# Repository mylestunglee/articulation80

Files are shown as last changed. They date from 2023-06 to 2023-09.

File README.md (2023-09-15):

# articulation80

The _articulation80_ keyboard is a split keyboard with 4x9 column splayed keys and 4 thumb keys. The name is inspired from articulated buses, where this keyboard has many connected blocks.

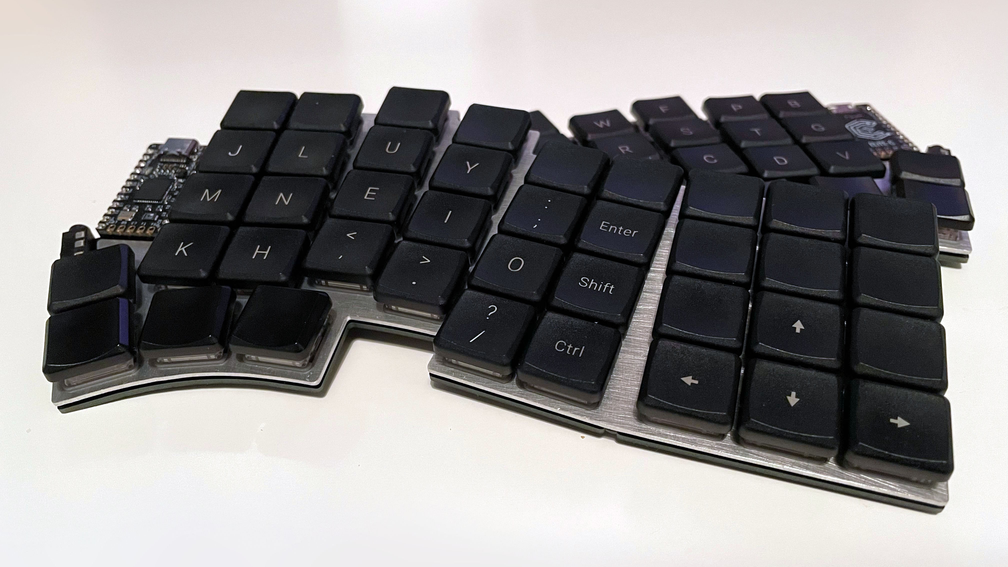
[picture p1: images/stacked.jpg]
Keyboard preview


It features:
- Kailh Choc V1 hotswap support with choc spacing
- A detachable inner number row with fixed outer number row
- A detachable numpad
- Serial or I2C connection between halves
- Pro Micro-compatible controller support
- No branding! If you are building this, you may want to add silk-screen to make soldering easier.

I took inspiration from many keyboards:
- The general snappable layout from [Breeze](https://www.afternoonlabs.com/breeze/)
- The pinky stagger from [Kyria](https://blog.splitkb.com/introducing-the-kyria/)
- The column splay and thumb cluster from [Hillside 52](https://github.com/mmccoyd/hillside)
- Many popular keyboards to determine a suitable wiring diagram for TRRS, such as the [Corne](https://github.com/foostan/crkbd)

## Repository Contents

| Name | Description |
|:-|:-|
| `pcb` | KiCad 7 project with symbol diagrams, footprints and 3D models included |
| `layout.FCStd` | FreeCad layout file outlining PCB and plate edges |
| `articulation80` | QMK files for firmware |

`scripts/info_json_matrix`

Generates `info.json` layout data for QMK by running `python generate_layout.py layout.csv`. `layout.csv` maps the visual key position with the pin row and column.

`scripts/verify_geometry`

 Translates points generated by FreeCad into KiCad. `export_points.py` is a script intended to run inside FreeCad to export all points into a text file, called `geometry.txt`. `update_geometry_markers.py` uses `geometry.txt` to aid the correct placement of components on the PCB and edges by placing dummy components as markers. Using the snap tool in KiCad, one can construct the edge by connecting markers. `remove_geometry_markers.py` removes these markers. Perhaps there is a more efficient way to make FreeCad and KiCad work together with existing plugins.

After soldering, copy the `articulation80` sub-directory into `qmk_firmware/keyboards`. Flash with:
```
qmk flash -kb articulation80 -km default -bl dfu-split-left
```
Replace `left` with `right` as necessary. This command assumes the Elite-C has been soldered using I2C. If not, change the bootloader in the command and in the `info.json` file.

## Build Instructions

This build is very similar to existing keyboards. Please refer to the inspired keyboards for full instructions.

### Build Parts

| Name | Count | Remarks |
|:-|:-|:-|
| PCB | 2 | |
| Plate | 2 | Ensure left and right are cut as required |
| Controller | 2 | A Pro Micro-compatible controller |
| TRRS jack | 2 | PJ-320A, ensure pins are through-hole|
| TRRS cable | 1 | Also called a 4-pin 3.5mm audio auxiliary cable |
| Reset button | 2 | Optional, PTS526 SM15 SMTR2 LFS recommended|
| Resistors | 2 | Optional, for I2C connection, RC1206FR-074K7 |
| Diode | 80* | SMD only, 1N4148W-TP, SOD-123 recommended |
| Hot swap key sockets | 80* | CPG135001S30 |
| Key Switch | 80* | |
| Key Cap | 80* | Ideally 6 key caps for thumbs |
| Hot swap controller sockets | 4 | Optional, 315-43-112-41-003000 or higher profile.|
| Hot swap pins | 48 | Optional, 3320-0-00-15-00-00-03-0 |
| Rubber feet | 12 | Can have more for stability, 6 recommended minimum for each side. SJ-5302 CLEAR recommended. |

*Adjust for number of keys desired.

See the [documentation on QMK](https://github.com/qmk/qmk_firmware/blob/master/docs/feature_split_keyboard.md) for how to solder the resistors. To minimise the complexity of the PCB, the left side controller is soldered upside down. There are four pads which connect the controller to the TRRS jack, these are intended to be soldered on the back side of the keyboard. From left to right with the back side facing up, if using serial connection, solder pads 1 and 4, otherwise if using I2C, solder 2, 3 and 4.

## More Images

Featuring MBK and MCC POM keycaps.

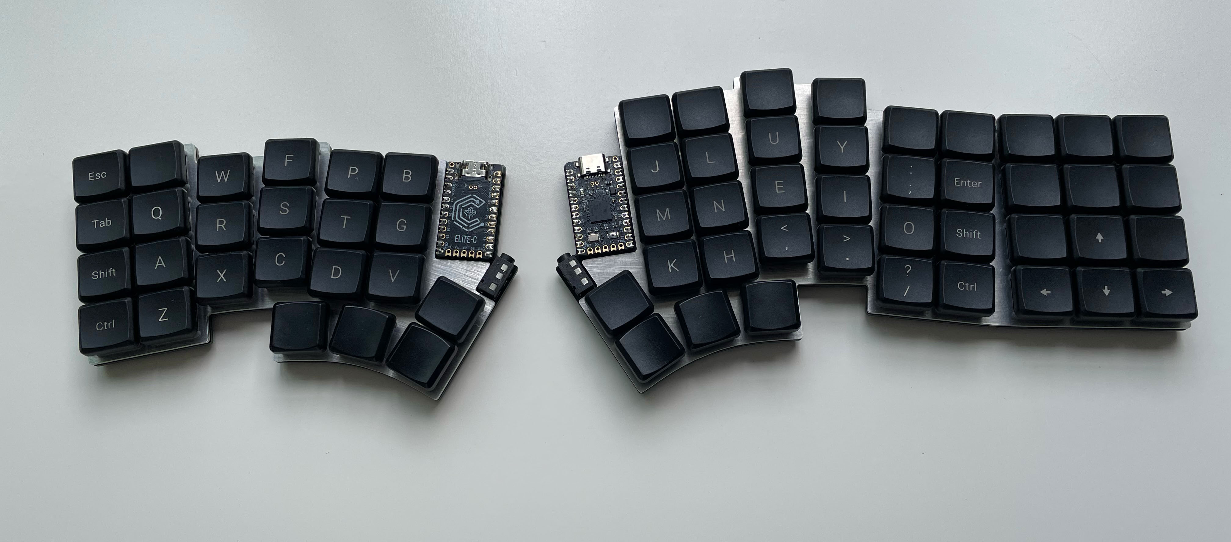
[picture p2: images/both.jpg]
Both sides

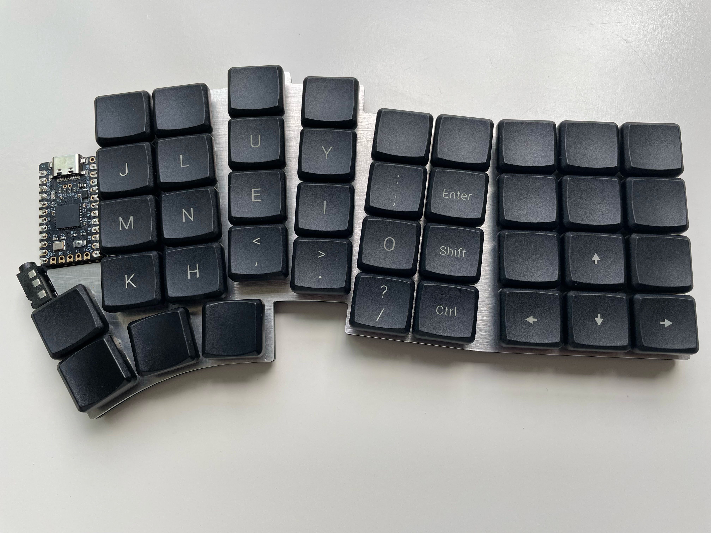
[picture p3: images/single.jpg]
Right side

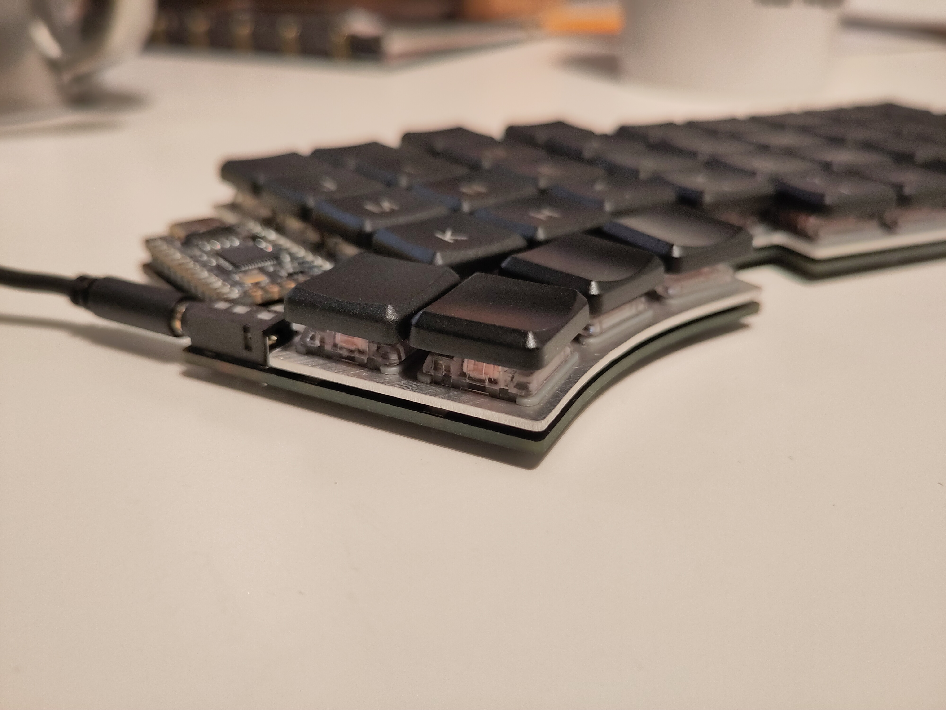
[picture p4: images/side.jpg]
Side view

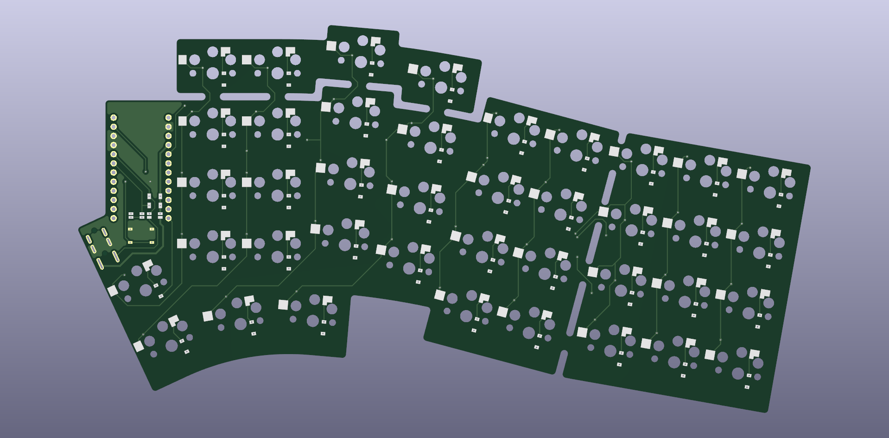
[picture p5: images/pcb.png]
Rendered PCB

Layout diagram

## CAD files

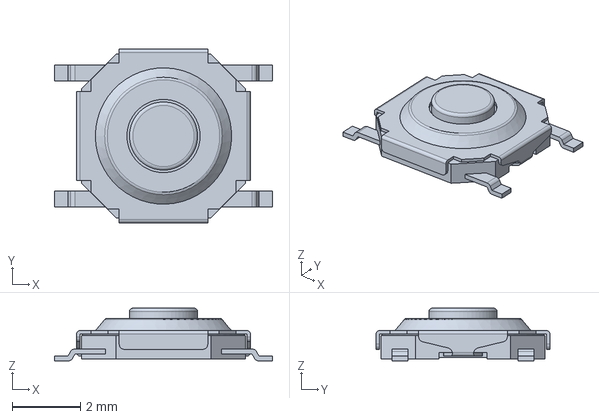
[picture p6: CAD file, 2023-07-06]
pcb/3dmodels/PTS526.stp
6.40 x 5.10 x 1.55 mm

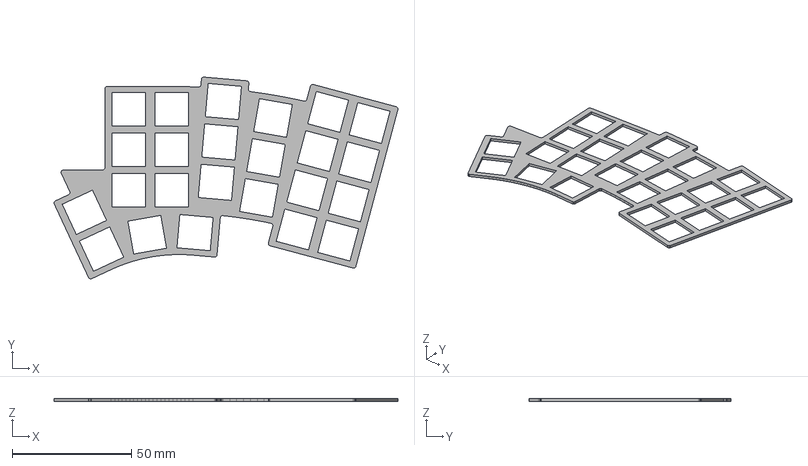
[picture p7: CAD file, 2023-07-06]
pcb/left-plate.step
144.2 x 84.6 x 1.20 mm

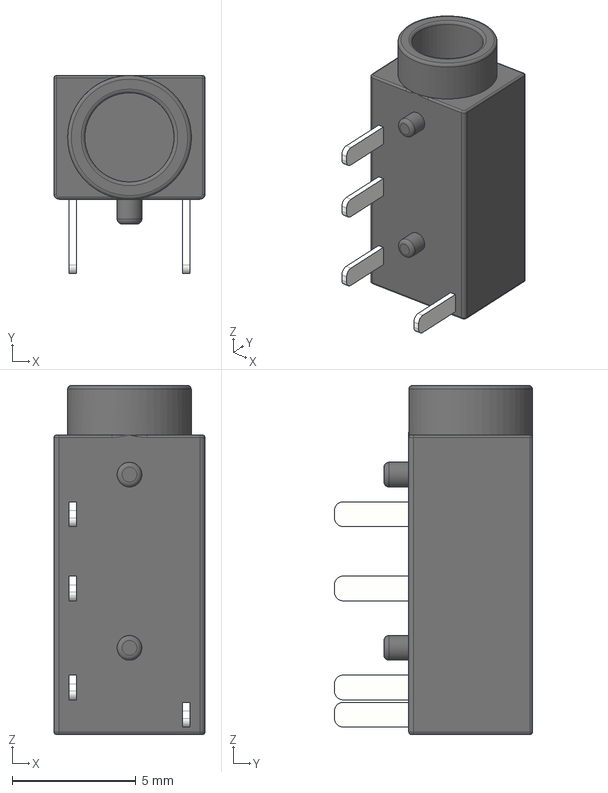
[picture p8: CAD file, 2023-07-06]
pcb/3dmodels/PJ-320A.step
6.10 x 8.00 x 14.1 mm

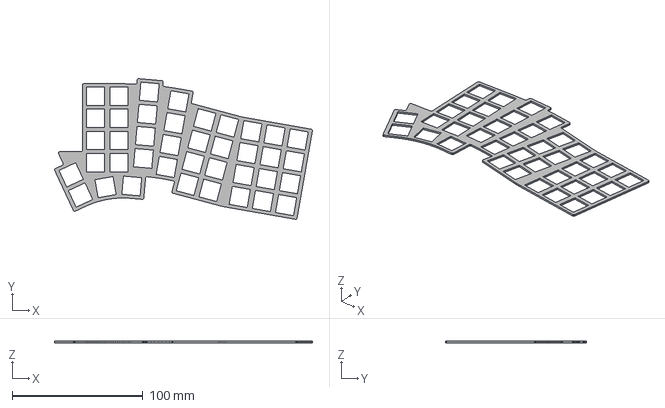
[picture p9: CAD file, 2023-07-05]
pcb/right-plate.step
197.4 x 107.7 x 1.20 mm

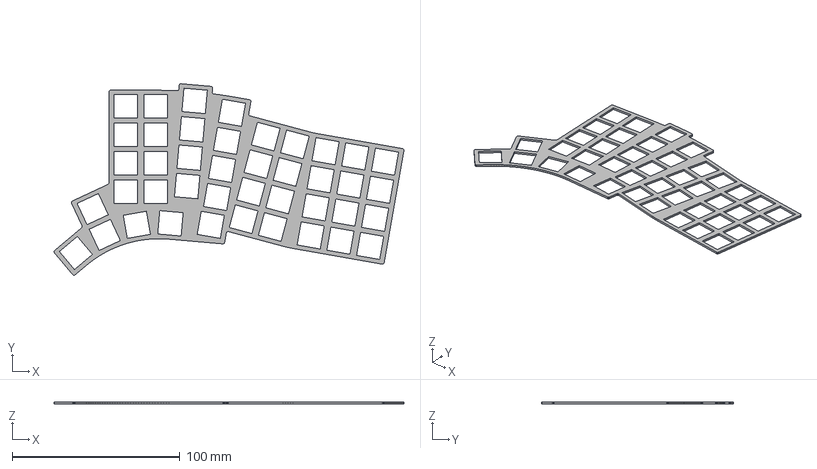
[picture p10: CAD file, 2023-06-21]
right plate.step
208.8 x 114.3 x 1.20 mm

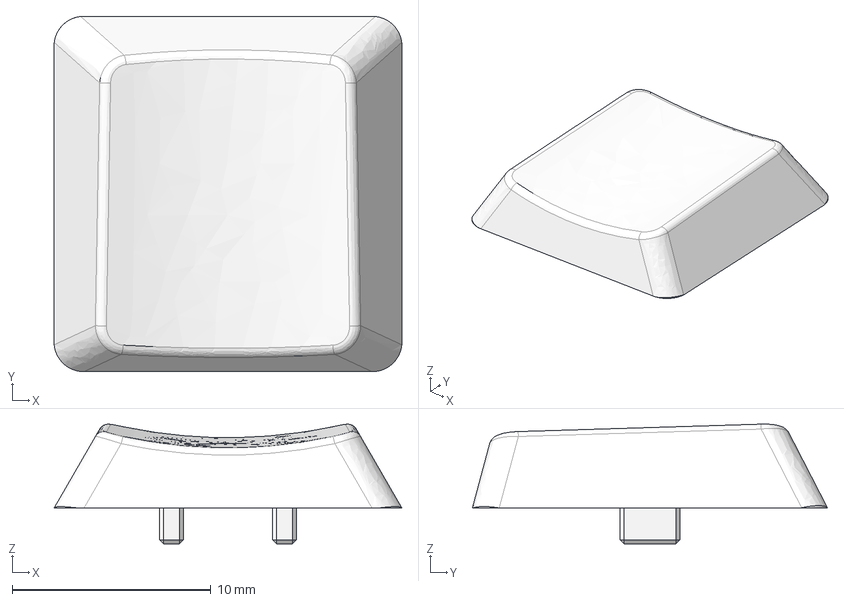
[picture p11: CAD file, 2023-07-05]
pcb/3dmodels/Kailh LP Choc PC Keycap.step
17.5 x 17.9 x 6.03 mm

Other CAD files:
layout.FCStd

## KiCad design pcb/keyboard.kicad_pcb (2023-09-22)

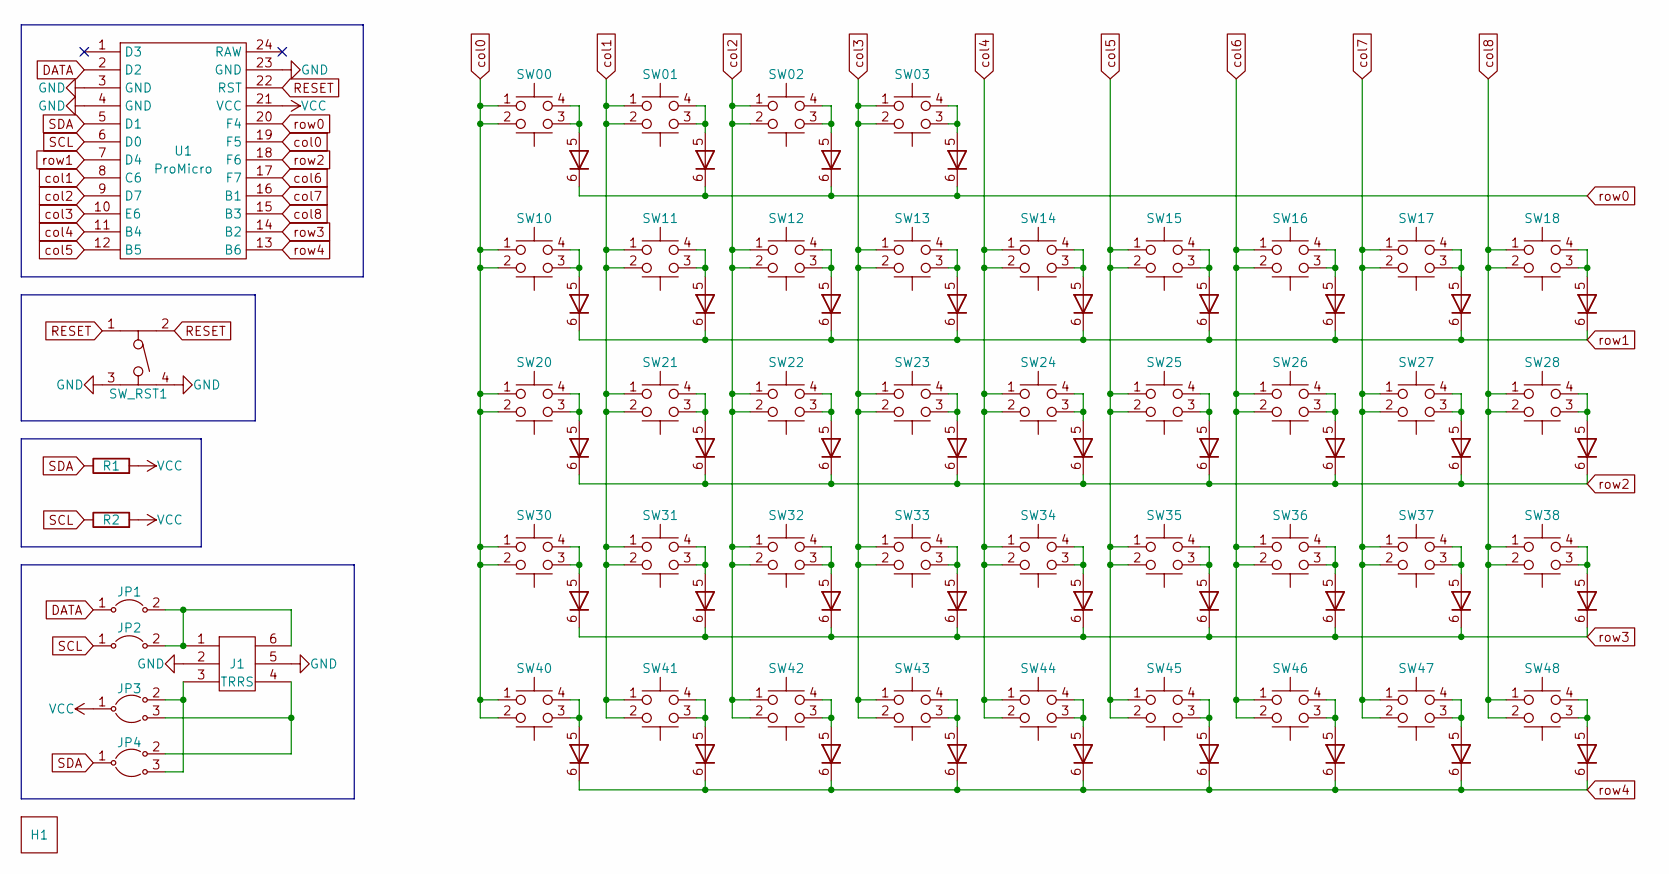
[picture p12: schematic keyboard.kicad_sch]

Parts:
H1: RightPlate
J1: TRRS; PJ-320A
JP1, JP2: Jumper
JP3, JP4: JumperSplit
R1, R2: R; SDR18
SW00, SW10, SW14, SW40, SW41: Key; KeyLeft
SW01, SW02, SW11, SW12, SW13, SW16, SW17, SW20, SW21, SW22, SW23, SW24, SW26, SW27, SW30, SW31, SW32, SW33, SW34, SW36, SW37, SW42, SW44, SW46, SW47: Key
SW03, SW15, SW18, SW25, SW28, SW35, SW38, SW43, SW45, SW48: Key; KeyRight
SW_RST1: PTS526; PTS525
U1: ProMicro

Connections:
DATA: JP1.1, U1.2 (D2)
GND: J1.2, J1.5, SW_RST1.3, SW_RST1.4, U1.3 (GND), U1.4 (GND), U1.23 (GND)
unnamed: J1.1, J1.6, JP1.2, JP2.2
unnamed: J1.3, JP3.2, JP4.3
unnamed: J1.4, JP3.3, JP4.2
unnamed: SW00.3, SW00.4, SW00.5
unnamed: SW01.3, SW01.4, SW01.5
unnamed: SW02.3, SW02.4, SW02.5
unnamed: SW03.3, SW03.4, SW03.5
unnamed: SW10.3, SW10.4, SW10.5
unnamed: SW11.3, SW11.4, SW11.5
unnamed: SW12.3, SW12.4, SW12.5
unnamed: SW13.3, SW13.4, SW13.5
unnamed: SW14.3, SW14.4, SW14.5
unnamed: SW15.3, SW15.4, SW15.5
unnamed: SW16.3, SW16.4, SW16.5
unnamed: SW17.3, SW17.4, SW17.5
unnamed: SW18.3, SW18.4, SW18.5
unnamed: SW20.3, SW20.4, SW20.5
unnamed: SW21.3, SW21.4, SW21.5
unnamed: SW22.3, SW22.4, SW22.5
unnamed: SW23.3, SW23.4, SW23.5
unnamed: SW24.3, SW24.4, SW24.5
unnamed: SW25.3, SW25.4, SW25.5
unnamed: SW26.3, SW26.4, SW26.5
unnamed: SW27.3, SW27.4, SW27.5
unnamed: SW28.3, SW28.4, SW28.5
unnamed: SW30.3, SW30.4, SW30.5
unnamed: SW31.3, SW31.4, SW31.5
unnamed: SW32.3, SW32.4, SW32.5
unnamed: SW33.3, SW33.4, SW33.5
unnamed: SW34.3, SW34.4, SW34.5
unnamed: SW35.3, SW35.4, SW35.5
unnamed: SW36.3, SW36.4, SW36.5
unnamed: SW37.3, SW37.4, SW37.5
unnamed: SW38.3, SW38.4, SW38.5
unnamed: SW40.3, SW40.4, SW40.5
unnamed: SW41.3, SW41.4, SW41.5
unnamed: SW42.3, SW42.4, SW42.5
unnamed: SW43.3, SW43.4, SW43.5
unnamed: SW44.3, SW44.4, SW44.5
unnamed: SW45.3, SW45.4, SW45.5
unnamed: SW46.3, SW46.4, SW46.5
unnamed: SW47.3, SW47.4, SW47.5
unnamed: SW48.3, SW48.4, SW48.5
RESET: SW_RST1.1, SW_RST1.2, U1.22 (RST)
SCL: JP2.1, R2.1, U1.6 (D0)
SDA: JP4.1, R1.1, U1.5 (D1)
VCC: JP3.1, R1.2, R2.2, U1.21 (VCC)
col0: SW00.1, SW00.2, SW10.1, SW10.2, SW20.1, SW20.2, SW30.1, SW30.2, SW40.1, SW40.2, U1.19 (F5)
col1: SW01.1, SW01.2, SW11.1, SW11.2, SW21.1, SW21.2, SW31.1, SW31.2, SW41.1, SW41.2, U1.8 (C6)
col2: SW02.1, SW02.2, SW12.1, SW12.2, SW22.1, SW22.2, SW32.1, SW32.2, SW42.1, SW42.2, U1.9 (D7)
col3: SW03.1, SW03.2, SW13.1, SW13.2, SW23.1, SW23.2, SW33.1, SW33.2, SW43.1, SW43.2, U1.10 (E6)
col4: SW14.1, SW14.2, SW24.1, SW24.2, SW34.1, SW34.2, SW44.1, SW44.2, U1.11 (B4)
col5: SW15.1, SW15.2, SW25.1, SW25.2, SW35.1, SW35.2, SW45.1, SW45.2, U1.12 (B5)
col6: SW16.1, SW16.2, SW26.1, SW26.2, SW36.1, SW36.2, SW46.1, SW46.2, U1.17 (F7)
col7: SW17.1, SW17.2, SW27.1, SW27.2, SW37.1, SW37.2, SW47.1, SW47.2, U1.16 (B1)
col8: SW18.1, SW18.2, SW28.1, SW28.2, SW38.1, SW38.2, SW48.1, SW48.2, U1.15 (B3)
row0: SW00.6, SW01.6, SW02.6, SW03.6, U1.20 (F4)
row1: SW10.6, SW11.6, SW12.6, SW13.6, SW14.6, SW15.6, SW16.6, SW17.6, SW18.6, U1.7 (D4)
row2: SW20.6, SW21.6, SW22.6, SW23.6, SW24.6, SW25.6, SW26.6, SW27.6, SW28.6, U1.18 (F6)
row3: SW30.6, SW31.6, SW32.6, SW33.6, SW34.6, SW35.6, SW36.6, SW37.6, SW38.6, U1.14 (B2)
row4: SW40.6, SW41.6, SW42.6, SW43.6, SW44.6, SW45.6, SW46.6, SW47.6, SW48.6, U1.13 (B6)

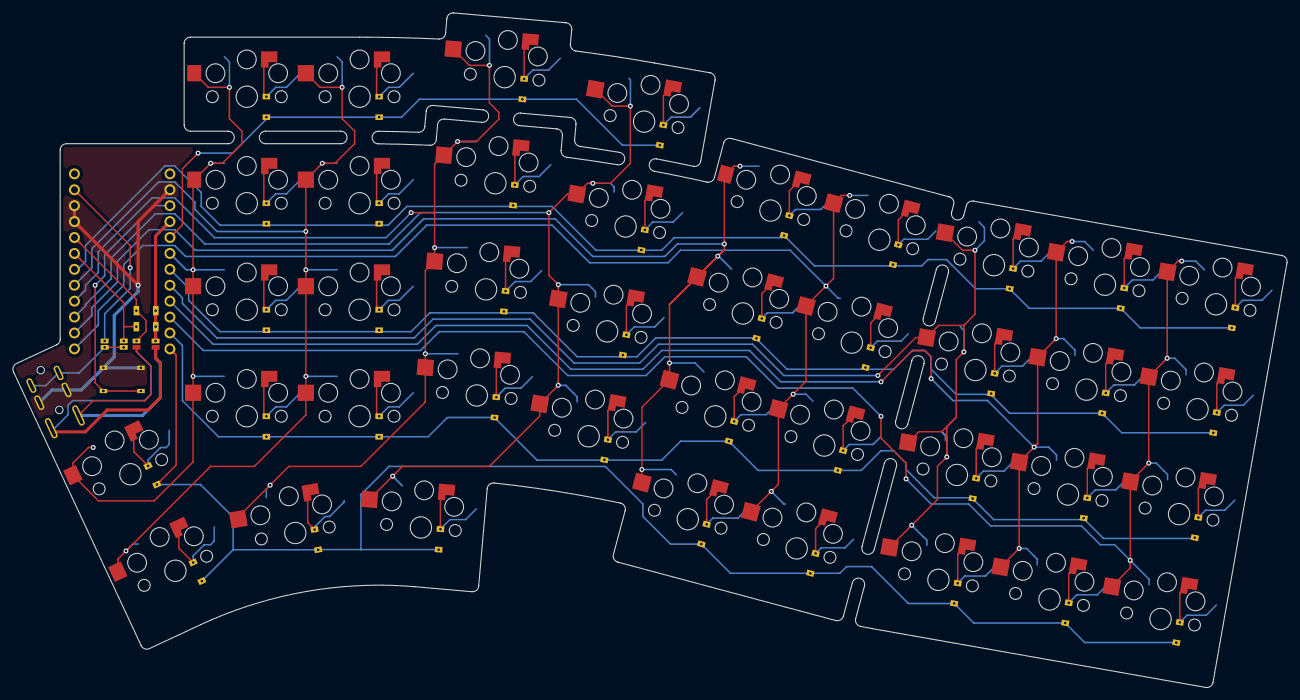
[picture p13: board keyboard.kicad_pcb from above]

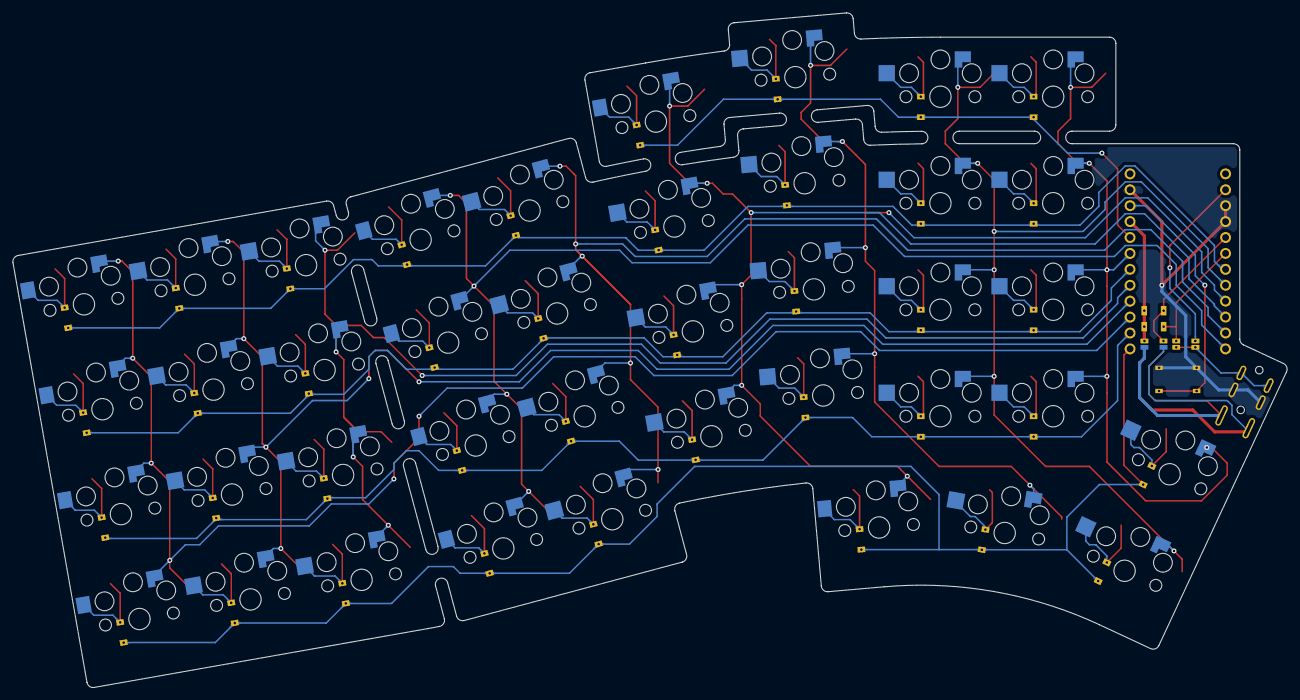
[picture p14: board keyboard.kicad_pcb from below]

Board: 2 copper layers, 203.4 x 107.7 mm, 50 parts (3 on the bottom side), 63 nets.

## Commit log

2023-06-19 added new jumpers
    [myles-keyboard.kicad_pcb, myles-keyboard.kicad_sch]
2023-06-19 rotate keyboard
    [myles-keyboard-backup.kicad_pcb, myles-keyboard.kicad_pcb]
2023-06-20 move footprints
    [myles-keyboard.kicad_pcb]
2023-06-20 everything but pads in position
    [myles-keyboard.kicad_pcb]
2023-06-20 add plates
    [left plate.kicad_pcb, myles-keyboard.kicad_pcb, right plate.kicad_pcb]
2023-06-20 move diodes
    [myles-keyboard.kicad_pcb]
2023-06-21 add 3d model for plate for main pcb
    [left plate.kicad_pcb, myles-keyboard.kicad_pcb, right plate.kicad_pcb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]
2023-06-21 rearrange TRRS jack
    [myles-keyboard.kicad_pcb, myles-keyboard.kicad_sch]
2023-06-21 reorder jumpers
    [myles-keyboard.kicad_pcb, myles-keyboard.kicad_sch]
2023-06-22 start adding traces
    [myles-keyboard.kicad_pcb]
2023-06-24 add lots of traces
    [myles-keyboard.kicad_pcb, myles-keyboard.kicad_sch]
2023-06-26 setup wiring around promicro
    [myles-keyboard.kicad_pcb]
2023-06-26 draft wiring
    [myles-keyboard.kicad_pcb, myles-keyboard.kicad_sch]
2023-06-26 tidy wiring
    [myles-keyboard.kicad_pcb, myles-keyboard.kicad_sch]
2023-06-27 add fill zones
    [myles-keyboard.kicad_pcb]
2023-06-27 redo zones
    [myles-keyboard.kicad_pcb]
2023-06-27 move origin
    [myles-keyboard.kicad_pcb]
2023-06-29 remove OLED
    [myles-keyboard.kicad_pcb, myles-keyboard.kicad_sch]
2023-06-30 complete draft tracing
    [myles-keyboard.kicad_pcb]
2023-07-01 adjust pad size for key; reroute with new pads
    [myles-keyboard.kicad_pcb, switch-layout.FCStd]
2023-07-02 add reset button 3d model and trim 1m off TRRS jack front
    [myles-keyboard.kicad_pcb, myles-keyboard.kicad_sch]
2023-07-03 move switch layout outside of repo
    [switch-layout.FCStd]
2023-07-03 rename files
    [keyboard.kicad_pcb, keyboard.kicad_sch, left-plate.kicad_pcb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]
2023-07-03 adjust plates and pcb; remove reset button
    [keyboard.kicad_pcb, left-plate.kicad_pcb, right-plate.kicad_pcb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]
2023-07-03 add symbol and footprint for new thin reset button
    [keyboard.kicad_pcb, keyboard.kicad_sch]
2023-07-03 update plates
    [keyboard.kicad_pcb, left-plate.kicad_pcb, right-plate.kicad_pcb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]
2023-07-03 reroute with new layout; use less vias in each switch
    [keyboard.kicad_pcb]
2023-07-04 add layout files
    [layout.FCStd]
2023-07-04 remove two thumb keys
    [keyboard.kicad_pcb, keyboard.kicad_sch, layout.FCStd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]
2023-07-04 remove area under palm
    [keyboard.kicad_pcb, layout.FCStd, left-plate.kicad_pcb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]
2023-07-04 improve traces
    [keyboard.kicad_pcb]
2023-07-05 fix more traces
    [Kailh LP Choc PC Keycap.step, PTS525SK08.stp, keyboard.kicad_pcb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]
2023-07-05 improve more traces
    [keyboard.kicad_pcb, layout.FCStd]
2023-07-05 curve a few edges
    [keyboard.kicad_pcb, layout.FCStd, left-plate.kicad_pcb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]
2023-07-06 remove rounded pro micro pin and widen TRRS traces
    [keyboard.kicad_pcb]
2023-07-06 update reset button
    - move 3d model into directory
    - update PTS525 to PTS526
    - centre align reset button with pro micro
    [PJ-320A.step, PTS525SK08.stp, PTS526.stp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]
2023-07-06 add left plate
    [left-plate.step]
2023-07-06 export gerber
    [keyboard.kicad_pcb]
2023-07-06 do not have vias on pads
    [keyboard.kicad_pcb]
2023-07-07 make reset button double sided and remove silk screen
    [keyboard.kicad_pcb]
2023-07-07 correct PTS526 pad sizes
    [keyboard.kicad_pcb]
2023-07-07 optimise layout
    [layout.FCStd]
2023-07-07 add mask for drill holes
    [keyboard.kicad_pcb]
2023-07-09 reroute TRRS
    [keyboard.kicad_pcb]
2023-07-09 add teardrops
    [keyboard.kicad_pcb]
2023-07-09 correct TRRS footprint
    [keyboard.kicad_pcb]
2023-07-10 make resistor footprint double sided
    [keyboard.kicad_pcb]
2023-08-26 use offical KiCad gitignore
2023-09-12 replace circle in arcs, generate images
    [layout.FCStd]
2023-09-13 move pcb files into pcb directory
    [Kailh LP Choc PC Keycap.step, PJ-320A.step, PTS526.stp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]
2023-09-13 add readme and scripts
    [layout.csv]
2023-09-22 move text to user drawing layer
    [keyboard.kicad_pcb]
2023-09-22 ignore pcb export zip
2023-10-08 fix right plate name
